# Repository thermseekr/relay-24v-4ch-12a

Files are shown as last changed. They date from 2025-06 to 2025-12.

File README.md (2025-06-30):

# RELAY-24V-4CH-12A

Relay board with 4x 24 VDC relays. This board is designed to be used togheter with [ESP-24V-16CH](https://github.com/thermseekr/esp-24v-16ch) and [ESP-24V-32CH](https://github.com/thermseekr/esp-24v-32ch), but can be driven by any 24V control circuit compatible with NPN inputs.

The dimensions are such that the boards can be mounted on a PCB DIN rail holder from the Brazilian manufacturer Metaltex, check [here](https://www.metaltex.com.br/produtos/componentes/suportes/sp7-suporte-para-montagem-de-placa-de-circuito-impresso-em-trilho-din) for details.

Board uses Omron 16A relays and is limited to 12A/channel per copper trace capacity.

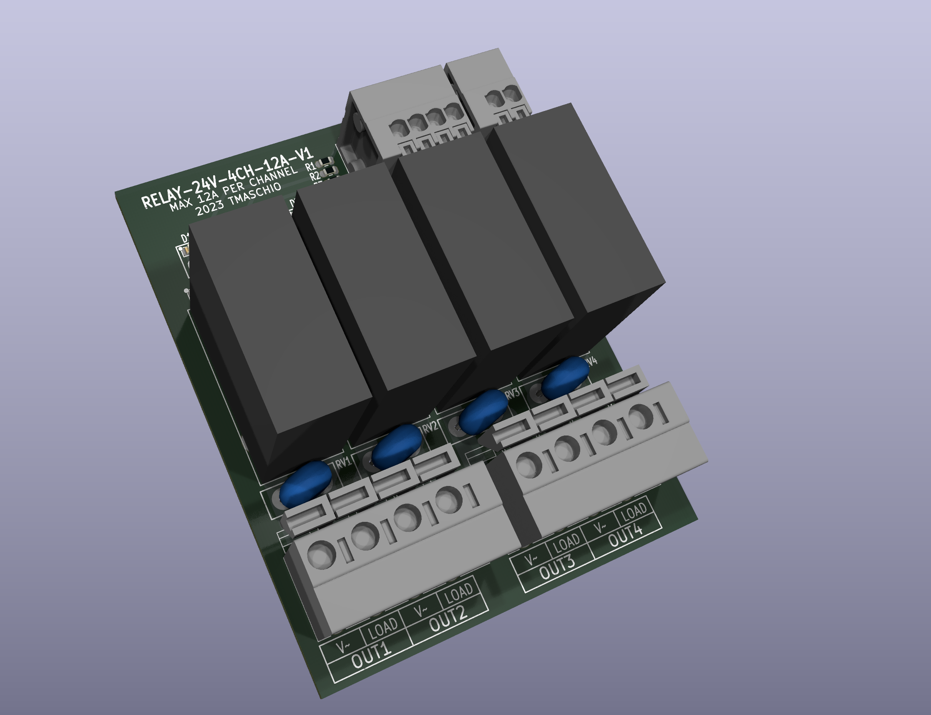
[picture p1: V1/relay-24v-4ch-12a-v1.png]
RELAY-24V-4CH-12A V1


## LICENSE

This project is licensed under the [Creative Commons BY-NC 4.0 License](https://creativecommons.org/licenses/by-nc/4.0/).
Commercial use is not permitted without prior written consent. See the [LICENSE.txt](LICENSE.txt) file for details.

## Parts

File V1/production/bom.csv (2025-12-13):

Designator | Footprint | Quantity | Value | LCSC Part #
D1, D3, D5, D7 | 0603 | 4 | WHITE | C2290
D2, D4, D6, D8 | D_SOD-123 | 4 | 1N4148 | C81598
J1 | TerminalBlock_Dibo_DB141V-2.54-2P _1x02_P2.54mm_Vertical | 1 | DB141V-2.54-2P | C2898744
J2 | TerminalBlock_Dibo_DB141V-2.54-4P _1x04_P2.54mm_Vertical | 1 | DB141V-2.54-4P | C2898746
J3, J4 | TerminalBlock_Dibo_DB142V-5.08-4P_1x04_P5.08mm_Vertical | 2 | DB142V-5.08-4P | C2898701
K1, K2, K3, K4 | Relay_SPST_Omron_G5PZ-1A | 4 | G5PZ-1A | C6719448
R1, R2, R3, R4 | 0603 | 4 | 10k/100mW | C25804
RV1, RV2, RV3, RV4 | RV_Disc_D9.50mm_W3.6mm_P5.08mm | 4 | 275VAC | C2761646

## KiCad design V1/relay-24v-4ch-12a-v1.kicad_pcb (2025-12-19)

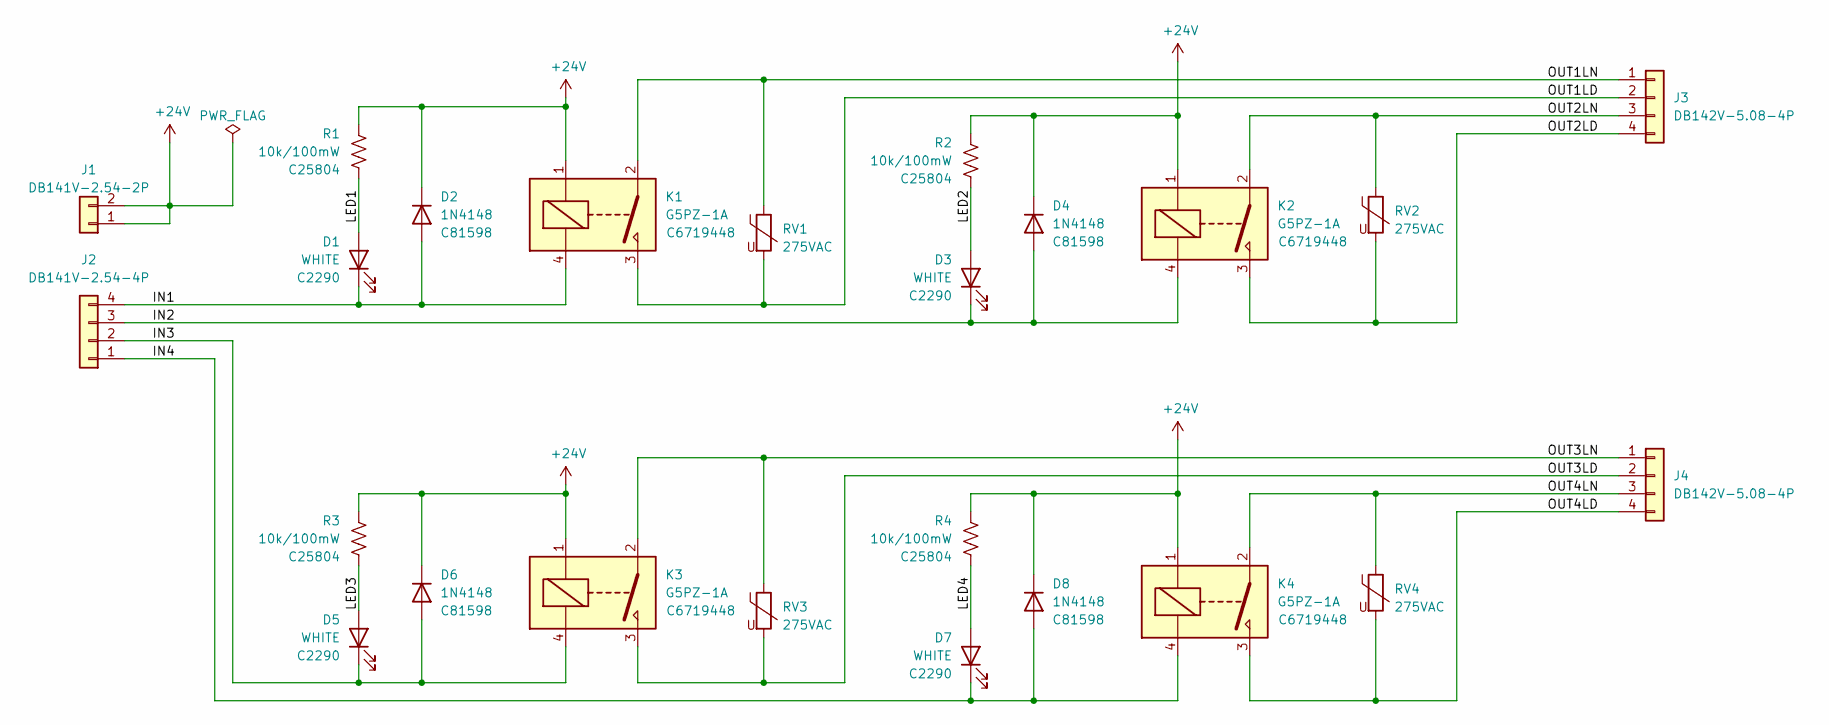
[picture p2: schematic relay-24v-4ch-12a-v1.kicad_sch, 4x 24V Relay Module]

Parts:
D1, D3, D5, D7: WHITE; LED_0603_1608Metric; Mfr PN KT-0603W; LCSC Part # C2290
D2, D4, D6, D8: 1N4148; D_SOD-123; Mfr PN 1N4148W; LCSC Part # C81598
J1: DB141V-2.54-2P; TerminalBlock_Dibo_DB141V-2.54-2P_1x02_P2.54mm_Vertical; Mfr PN DB141V-2.54-2P-GN; JLCPCB BOM 1
J2: DB141V-2.54-4P; TerminalBlock_Dibo_DB141V-2.54-4P_1x04_P2.54mm_Vertical; Mfr PN DB141V-2.54-4P-GN; JLCPCB BOM 1
J3, J4: DB142V-5.08-4P; TerminalBlock_Dibo_DB142V-5.08-4P_1x04_P5.08mm_Vertical; Mfr PN DB142V-5.08-4P-GN; JLCPCB BOM 1
K1, K2, K3, K4: G5PZ-1A; Relay_SPST_Omron_G5PZ-1A; Mfr PN G5PZ-1A-E DC24V; JLCPCB BOM 1
R1, R2, R3, R4: 10k/100mW; R_0603_1608Metric; Mfr PN 0603WAF1002T5E; LCSC Part # C25804
RV1, RV2, RV3, RV4: 275VAC; RV_Disc_D9.50mm_W3.6mm_P5.08mm; Mfr PN RM07D431KC1IE100; JLCPCB BOM 1

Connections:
+24V: D2.1 (K), D4.1 (K), D6.1 (K), D8.1 (K), J1.1, J1.2, K1.1, K2.1, K3.1, K4.1, R1.1, R2.1, R3.1, R4.1
/IN1: D1.1 (K), D2.2 (A), J2.4, K1.4
/IN2: D3.1 (K), D4.2 (A), J2.3, K2.4
/IN3: D5.1 (K), D6.2 (A), J2.2, K3.4
/IN4: D7.1 (K), D8.2 (A), J2.1, K4.4
/LED1: D1.2 (A), R1.2
/LED2: D3.2 (A), R2.2
/LED3: D5.2 (A), R3.2
/LED4: D7.2 (A), R4.2
/OUT1LD: J3.2, K1.3, RV1.2
/OUT1LN: J3.1, K1.2, RV1.1
/OUT2LD: J3.4, K2.3, RV2.2
/OUT2LN: J3.3, K2.2, RV2.1
/OUT3LD: J4.2, K3.3, RV3.2
/OUT3LN: J4.1, K3.2, RV3.1
/OUT4LD: J4.4, K4.3, RV4.2
/OUT4LN: J4.3, K4.2, RV4.1

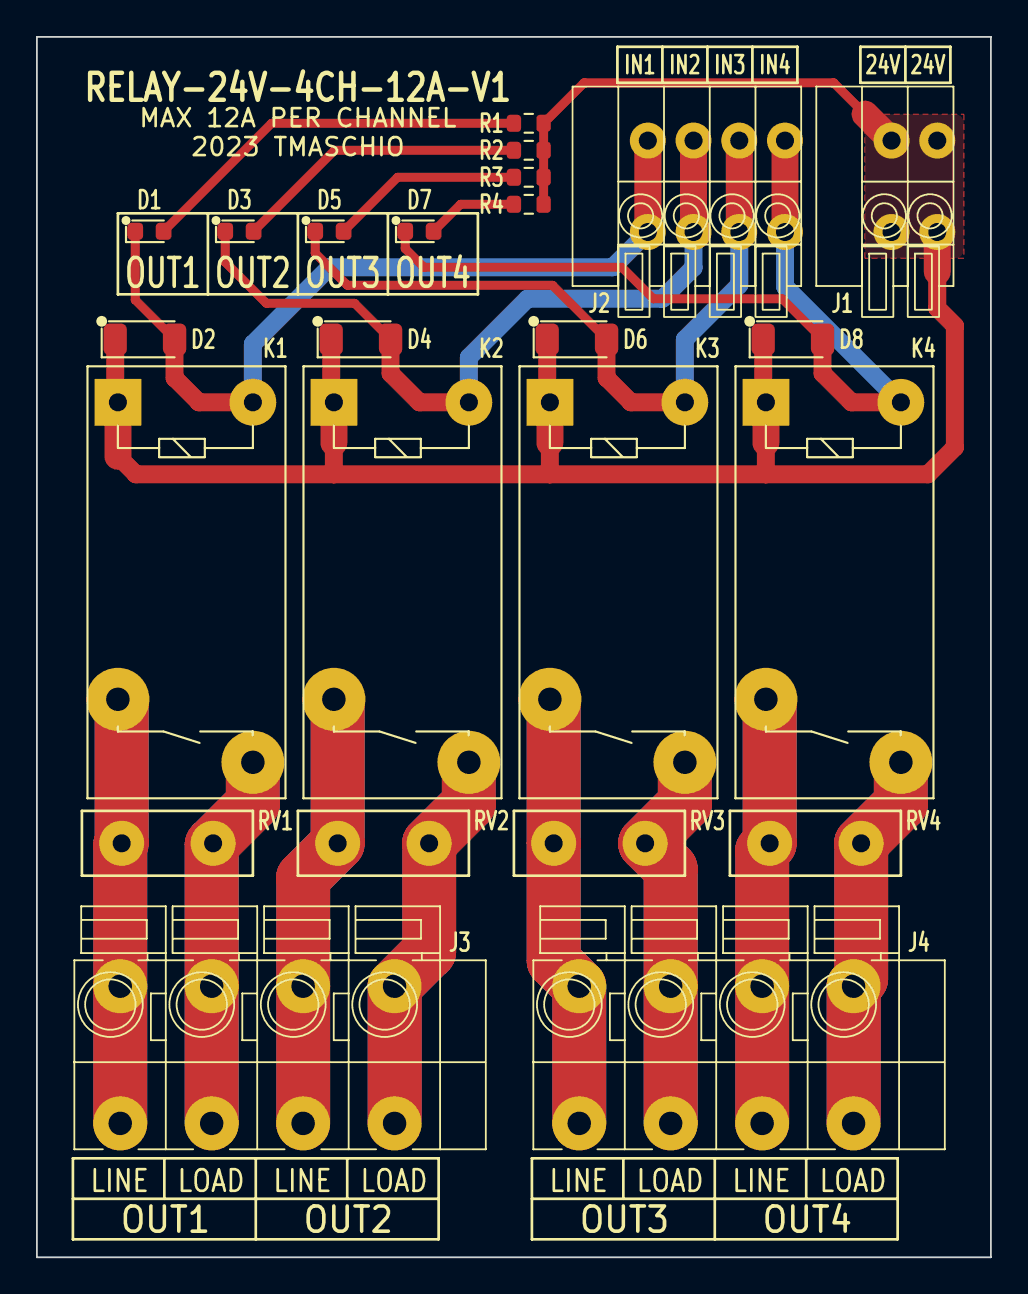
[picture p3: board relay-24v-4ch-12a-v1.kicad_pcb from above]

Board: 2 copper layers, 53.0 x 67.8 mm, 24 parts (0 on the bottom side), 17 nets.

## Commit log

2025-06-22 Updated connectors
    [relay-24v-4ch-12a-v1.kicad_pcb, relay-24v-4ch-12a-v1.kicad_sch]
2025-12-11 Revision before manufacturing
    [bom.csv, designators.csv, positions.csv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]
2025-12-13 Review before fabrication
    [bom.csv, relay-24v-4ch-12a-v1.kicad_pcb, relay-24v-4ch-12a-v1.kicad_sch]
2025-12-19 Revising before manufacturing.
    [relay-24v-4ch-12a-v1.kicad_pcb, relay-24v-4ch-12a-v1.kicad_sch]
